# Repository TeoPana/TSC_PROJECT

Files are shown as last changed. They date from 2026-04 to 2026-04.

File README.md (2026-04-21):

# TSC_PROJECT
                    DIAGRAMA

                 +----------------------+
                 |      Baterie LiPo    |
                 +----------+-----------+
                            |
                            v
                 +----------------------+
                 |   Bloc alimentare    |
                 |  Charger / DC-DC     |
                 |  VBUS / VBAT / 3V3   |
                 +----------+-----------+
                            |
                            v
                 +----------------------+
                 |      nRF52840        |
                 | MCU + BLE + control  |
                 +---+---------+-----+--+
                     |         |     |
          SPI        |         |     | GPIO
                     |         |     |
                     v         v     v
          +---------------+  +-------------+  +-------------+
          |  Display      |  |  Senzori    |  |  Butoane    |
          |  e-paper      |  |  IMU / I2C  |  |  User Input |
          +---------------+  +-------------+  +-------------+

                     |
                     | SWD / test pads
                     v
              +------------------+
              | Debug / Program  |
              | SWDIO / SWDCLK   |
              +------------------+

                     |
                     | RF matching
                     v
              +------------------+
              | Antena 2.4 GHz   |
              +------------------+

USB-C ---> Alimentare / Service / Debug

Descriere Hardware - Proiect Smartwatch
Ce am vrut să fac aici e un smartwatch care are la bază microcontrolerul nRF52840. L-am ales pe ăsta pentru că e destul de puternic, are nucleu ARM Cortex-M4F și vine deja cu partea de radio de 2.4 GHz integrată, deci ne scapă de multe bătăi de cap cu comunicarea. El se ocupă de tot: display, butoane, baterie și partea de bluetooth.

1. Cum e gândit sistemul
Toată treaba e alimentată de o baterie mică Li-Po. Am pus niște test pad-uri pe placă ca să o putem lipi ușor. Tensiunea trece printr-un etaj de conversie (un DC/DC) și apoi pleacă spre restul componentelor.

În mare, piesa centrală (nRF-ul) coordonează:

Ecranul de tip e-paper (care consumă super puțin);

Senzorii de pe magistrala serială;

Butoanele pentru utilizator;

Partea de programare (debug) și antena de radio.

Cam astea ar fi blocurile mari: alimentare, procesorul, afișajul, butoanele și partea de RF.

2. Alimentarea
Bateria Li-Po e legată direct la PCB. Ca să scoatem 3.3 V pentru microcontroler am folosit un convertor DC/DC step-up (mă rog, e de tip step-down pentru că bateria are cam 3.7V-4.2V, dar ideea e că stabilizează rail-ul principal).

Am pus și condensatori de filtrare, de 100 nF, pe care i-am înghesuit cât mai aproape de pinii de alimentare, ca să nu avem zgomot. Traseele de curent le-am făcut mai groase pe cablaj ca să nu se încălzească sau să avem căderi de tensiune. Am mers pe DC/DC în loc de regulator liniar (LDO) ca să țină bateria mai mult, că la un ceas e critică autonomia.

3. Creierul sistemului (nRF52840)
Ăsta e punctul central. nRF-ul face de toate: citește butoanele, trimite date la ecran și se ocupă de stările de „sleep” ca să economisească energie. L-am pus cam pe mijlocul plăcii ca să fie traseele scurte către toate componentele și să nu se bată cap în cap semnalele digitale cu cele de radio.

4. Display-ul și cum se vede imaginea
Ecranul e legat prin SPI. Am ales SPI pentru că e mult mai rapid ca I2C-ul și la un ecran grafic chiar ai nevoie de viteză ca să nu se vadă cum se desenează pixelii.
Semnalele pe care le folosim sunt: MOSI pentru date, SCK (ceasul), CS (ca să știe display-ul că vorbim cu el) și mai sunt pinii de Reset și Busy.

Conectorul pentru display e pus pe margine, ca să poată intra panglica aia flexibilă în carcasă fără să se îndoaie prea tare sau să atingă alte piese.

5. Senzori și alte conexiuni
Pentru restul senzorilor am folosit magistrala I2C. E mai simplu așa că folosim doar doi pini (SDA și SCL) și putem pune mai mulți senzori pe aceleași fire. Am pus și rezistențe de pull-up, că altfel nu merge comunicarea pe I2C, e o greșeală clasică pe care am vrut să o evit.

6. Butoane (Input)
Am pus niște butoane fizice legate la pinii de tip GPIO. Din soft o să facem debouncing, dar pe parte de hardware sunt legate direct. Sunt puse pe margini ca să se pupe cu decupajele din carcasa printată.

7. USB-ul și programarea
Avem un conector USB-C pentru încărcare. Pentru programare n-am mai pus mufă specială că ocupa loc, așa că am scos niște pad-uri de test (SWDIO, SWDCLK, etc) unde ne putem lipi cu un programator extern când facem debug. E mult mai ok așa pentru faza de prototip.

8. Partea de antenă (RF)
Aici e cea mai sensibilă zonă. Am urmat schema de referință cu niște bobine și condensatori (rețeaua de adaptare) ca să avem impedanța de 50 ohmi.
Câteva reguli pe care le-am respectat la layout:

Antena e fix pe marginea plăcii;

Nu am pus masă (ground) sub antenă că altfel nu mai emite nimic;

Traseul e cât mai scurt, fără unghiuri dubioase care să bage paraziți.

9. Designul cablajului (Layout)
Am încercat să grupez piesele logic. Condensatorii de decuplare sunt „lipiți” de pinii de alimentare. N-am folosit unghiuri de 90 de grade la trasee (am mers pe 45) ca să arate profi și să evităm problemele de reflexie a semnalului. Am pus plan de masă pe ambele fețe și multe via-uri (via stitching) ca să fie totul ecranat bine, mai ales lângă zona de radio.

10. Bateria și consumul
Ceasul trebuie să stea aprins mult, deci am setat nRF-ul să stea în low-power cât mai mult timp. Ecranul e-paper ajută enorm aici, că el consumă curent doar când schimbi imaginea, în rest stă „degeaba”. Dacă nu facem refresh des, bateria ar trebui să țină destul de bine.

11. Cum se asamblează toate (Mecanică)
În modelul 3D am verificat dacă încap toate: PCB-ul, bateria Li-Po (care e destul de grasă) și ecranul. Mufa USB-C trebuie să iasă fix prin gaura din carcasă, altfel nu putem băga cablul la încărcat. Per total, totul pare că se aliniază ok și nu există piese care să se lovească între ele.

## Bill of Materials (BOM)

| Ref | Componentă | Valoare | Package | JLC Part | Datasheet |
|-----|---|---|---|---|---|
| C5, C7, C8, C12, C19 | Condensator decuplare | 100nF | 0201 | C1525 | https://datasheet.lcsc.com/lcsc/1811091111_Murata-Electronics-GRM011R60J104KE01D_C1525.pdf |
| C23, C27, C34, C42 | Condensator | 100nF | 0201 | C1525 | https://datasheet.lcsc.com/lcsc/1811091111_Murata-Electronics-GRM011R60J104KE01D_C1525.pdf |
| C15 | Condensator | 1µF | 0402 | C52923 | https://datasheet.lcsc.com/lcsc/1811151714_Samsung-Electro-Mechanics-CL05A105KO5NNNC_C52923.pdf |
| C24, C39 | Condensator bulk | 10µF | 0402 | C19702 | https://datasheet.lcsc.com/lcsc/1811091111_Samsung-Electro-Mechanics-CL05A106MQ5NUNC_C19702.pdf |
| C11 | Condensator RF | 100pF | 0201 | C57112 | https://datasheet.lcsc.com/lcsc/1811151714_Samsung-Electro-Mechanics-CL03C101JB3NNNC_C57112.pdf |
| R5, R7, R8 | Rezistor | 10kΩ | 0201 | C25744 | https://datasheet.lcsc.com/lcsc/1811090913_Yageo-RC0201FR-0710KL_C25744.pdf |
| R9, R_PWR_EPD | Rezistor | 10kΩ | 0201 | C25744 | https://datasheet.lcsc.com/lcsc/1811090913_Yageo-RC0201FR-0710KL_C25744.pdf |
| L2 | Inductor | 10µH | 0402 | C1046 | https://datasheet.lcsc.com/lcsc/1811091211_Sunlord-SWPA4020S100MT_C1046.pdf |
| SJ1 | Jumper | - | SMD | - | - |
| U1 | Microcontroller | nRF52840 | QFN/BGA | C87453 | https://infocenter.nordicsemi.com/pdf/nRF52840_PS_v1.1.pdf |
| USB | Conector USB-C | - | SMD | C165948 | https://datasheet.lcsc.com/lcsc/1811151713_TYPE-C-16PIN_C165948.pdf |
Toate componentele au fost selectate din biblioteca JLCPCB pentru a asigura compatibilitatea cu procesul de asamblare automată.

PINII nRF52840

Pinii i-am ales în funcție de cum dădea mai bine pe layout-ul PCB-ului și cum se optimiza mai ușor rutarea. Perifericele, gen SPI și I2C, le-am mapat pe pinii care erau cei mai aproape de componentele lor, special ca să ținem traseele scurte și să nu avem zgomot pe semnal.

Pinii cu funcții speciale (SWD și resetul) i-am lăsat doar pentru partea de debug, nu i-am folosit la alte semnale de uz general ca să nu ne încurcăm. Pentru semnalele de viteză mare, cum e SPI-ul, am mers pe conexiuni cât mai scurte și directe, în timp ce pe alea mai lente (I2C sau GPIO-urile) le-am plasat mai flexibil, pe unde am mai găsit loc pe placă.

Aveam si componenta 3D a TC2030-IDC ului, dar dupa ce am vorbit cu laborantul despre problema ca nu ar incapea in carcasa toate acele cabluri, mi s-a spus ca trebuie sa sterg acel model, si doar sa pun un rectangle deasupra lui ca sa acopar acele gauri.

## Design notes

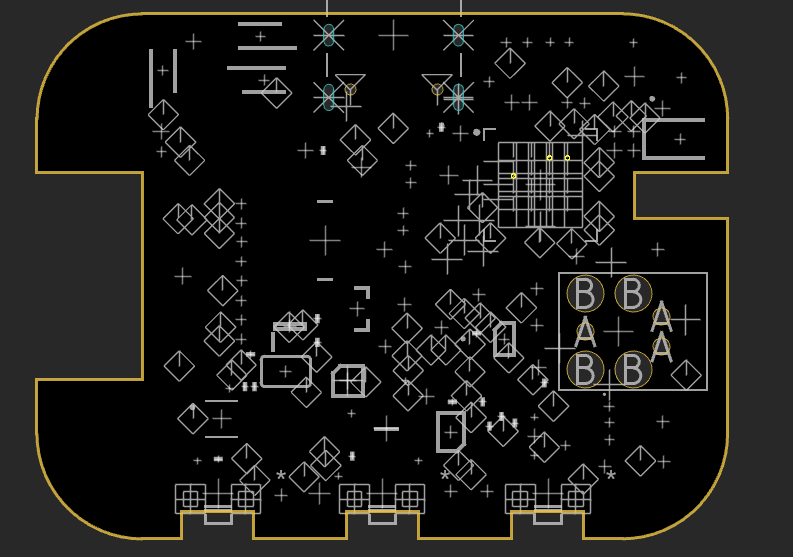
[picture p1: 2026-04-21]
Images/Screenshot 2026-04-21 045611.png

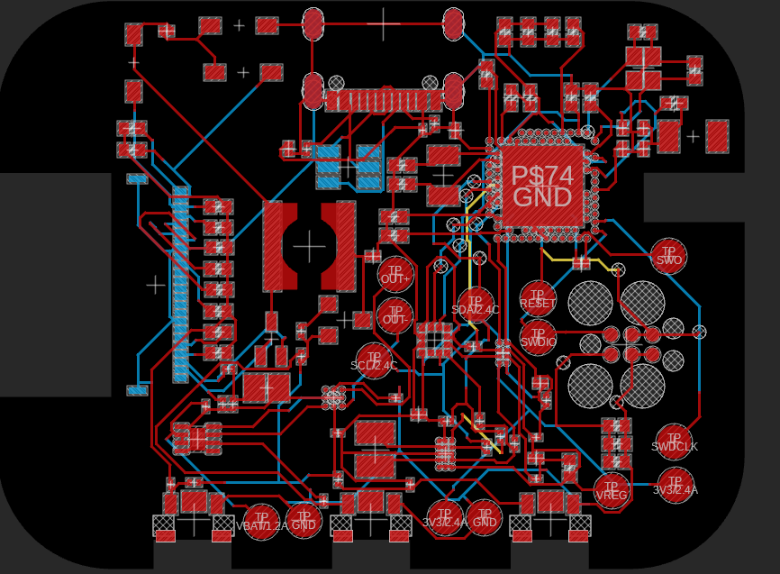
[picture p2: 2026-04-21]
Images/Screenshot 2026-04-21 045701.png

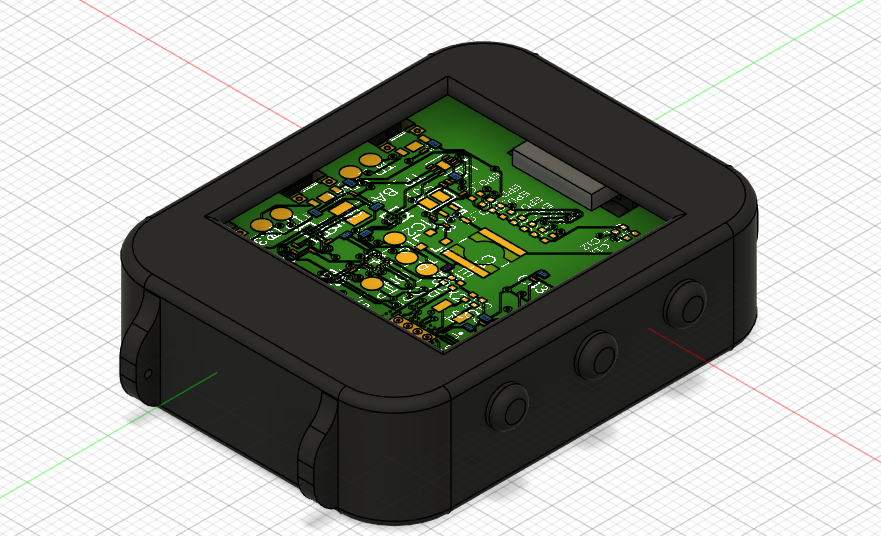
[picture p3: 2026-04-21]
Images/Screenshot 2026-04-21 045815.png

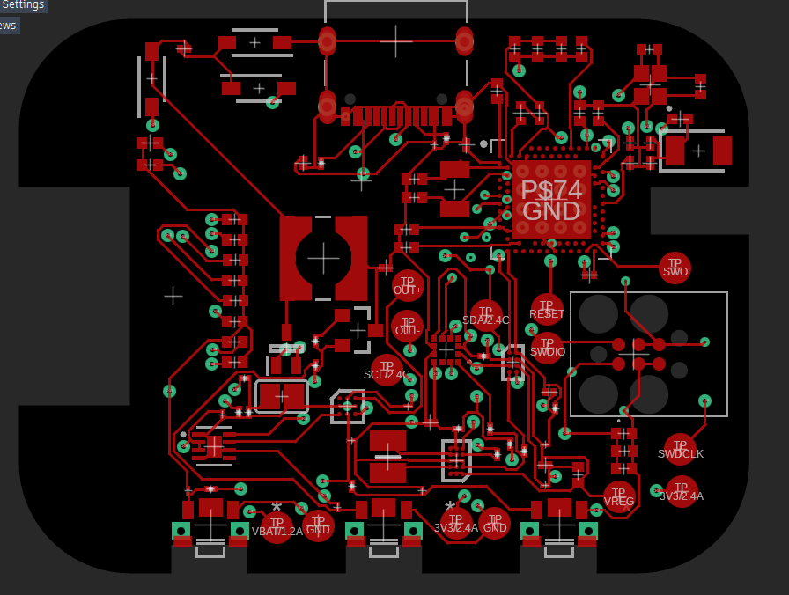
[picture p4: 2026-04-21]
Images/Screenshot 2026-04-21 045517.png

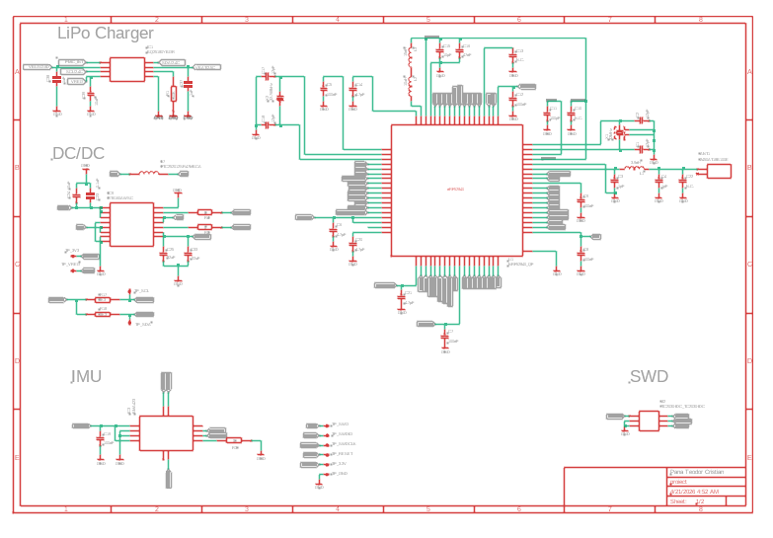
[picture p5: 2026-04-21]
Images/Screenshot 2026-04-21 045401.png

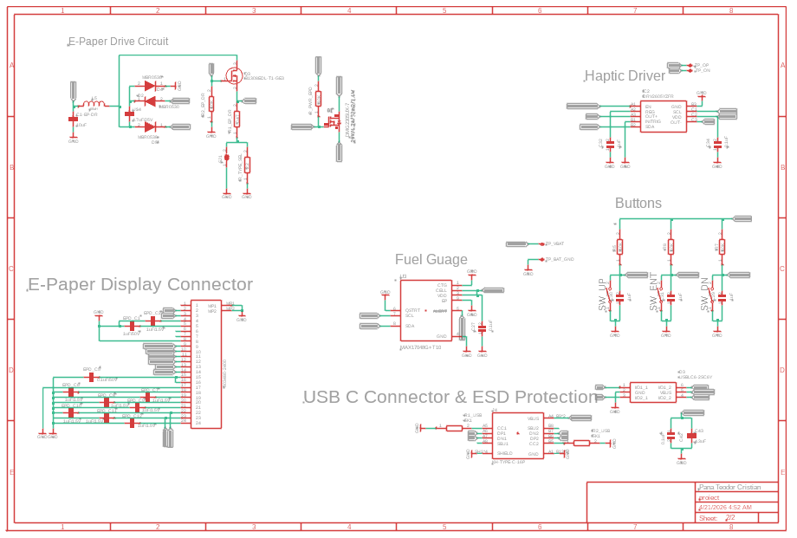
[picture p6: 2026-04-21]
Images/Screenshot 2026-04-21 045320.png

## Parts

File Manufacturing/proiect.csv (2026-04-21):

Qty | Value | Device | Package | Parts | Description | ARROW_PART_NUMBER | ARROW_PRICE-STOCK | AVAILABILITY | CHECK_PRICES | COPYRIGHT | DESCRIPTION | DIGI-KEY_PART_NUMBER_1 | DIGI-KEY_PART_NUMBER_2 | DIGI-KEY_PART_NUMBER_3 | HEIGHT | JLCPCB | MANUFACTURER_NAME | MANUFACTURER_PART_NUMBER | MF | MFR_NAME | MOUSER_PART_NUMBER | MOUSER_PRICE-STOCK | MP | PACKAGE | POPULARITY | PRICE | PROD_ID | PURCHASE-URL | SNAPEDA_LINK | TP_SIGNAL_NAME | VALUE
1 |  | ESP32_C6_LIBRARY_7_JUMPER_SJ | ESP32_C6_LIBRARY_7_JUMPER_SJ | SJ1 | SMD solder JUMPER |  |  |  |  |  |  |  |  |  |  |  |  |  |  |  |  |  |  |  | 3
3 | 0 | CPF0201D7K68C1_CPF0201D7K68C1 | CPF0201D7K68C1_0201 | R2, R3, R4 | 7.68k 0201 Thin Film Surface Mount Fixed Resistor +/-0.5% 0.031W CPF0201D7K68C1
4 | 0.1uF | GRM011R60J152KE01L_2_GRM011R60J152KE01L | GRM011R60J152KE01L_2_CAPC0201X13N | C23, C27, C34, C42 | Check availability |  |  | In Stock | https://www.snapeda.com/parts/GRM011R60J152KE01L/Murata/view-part/?ref=eda |  | SMD Capacitor X5R(EIA) with Capacitance: 1500pF Tol. 10%. Rated Voltage: 6.3Vdc |  |  |  |  |  |  |  | Murata |  |  |  | GRM011R60J152KE01L | 0201 Murata |  | None |  |  | https://www.snapeda.com/parts/GRM011R60J152KE01L/Murata/view-part/?ref=snap
1 | 0.1uF/50V | PERFECT_0402_CAP_0402 | PERFECT_0402_0402 | EPD_C5 | 0402 (1005 Metric)
1 | 0.47 | CPF0201D7K68C1_CPF0201D7K68C1 | CPF0201D7K68C1_0201 | R1_EP_DR | 7.68k 0201 Thin Film Surface Mount Fixed Resistor +/-0.5% 0.031W CPF0201D7K68C1
4 | 100nF | NORDIC_NRF_3_CAPACITOR_0201_L | NORDIC_NRF_3_RESC0201_L | C5, C7, C8, C9 | Generic chip capacitor
2 | 100nF | PERFECT_0402_CAP_0402 | PERFECT_0402_0402 | C12, C19 | 0402 (1005 Metric)
1 | 100pF | PERFECT_0402_CAP_0402 | PERFECT_0402_0402 | C11 | 0402 (1005 Metric)
6 | 10K | CPF0201D7K68C1_CPF0201D7K68C1 | CPF0201D7K68C1_0201 | R1, R2_EP_DR, R5, R7, R8, R_PWR_EPD | 7.68k 0201 Thin Film Surface Mount Fixed Resistor +/-0.5% 0.031W CPF0201D7K68C1
2 | 10uF | NORDIC_NRF_3_CAPACITOR_0201_L | NORDIC_NRF_3_RESC0201_L | C1-EP-DR, C39 | Generic chip capacitor
1 | 10uF | PERFECT_0402_CAP_0402 | PERFECT_0402_0402 | C24 | 0402 (1005 Metric)
1 | 10uH | NORDIC_NRF_2_INDUCTOR_0402_L | NORDIC_NRF_2_RESC0402_L | L2 | Generic chip inductor
1 | 10µF | PERFECT_0402_CAP_0402 | PERFECT_0402_0402 | C15 | 0402 (1005 Metric)
4 | 12pF | PERFECT_0402_CAP_0402 | PERFECT_0402_0402 | C1, C2, C17, C18 | 0402 (1005 Metric)
1 | 15nH | NORDIC_NRF_2_INDUCTOR_0402_L | NORDIC_NRF_2_RESC0402_L | L3 | Generic chip inductor
2 | 1pF | NORDIC_NRF_3_CAPACITOR_0201_L | NORDIC_NRF_3_RESC0201_L | C3, C4 | Generic chip capacitor
1 | 1uF | GRM011R60J152KE01L_1_GRM011R60J152KE01L | GRM011R60J152KE01L_1_0201 | C38 | Check availability
5 | 1uF | GRM011R60J152KE01L_2_GRM011R60J152KE01L | GRM011R60J152KE01L_2_CAPC0201X13N | C29\, C30, C31, C32, C37 | Check availability |  |  | In Stock | https://www.snapeda.com/parts/GRM011R60J152KE01L/Murata/view-part/?ref=eda |  | SMD Capacitor X5R(EIA) with Capacitance: 1500pF Tol. 10%. Rated Voltage: 6.3Vdc |  |  |  |  |  |  |  | Murata |  |  |  | GRM011R60J152KE01L | 0201 Murata |  | None |  |  | https://www.snapeda.com/parts/GRM011R60J152KE01L/Murata/view-part/?ref=snap
8 | 1uF/1.5V | PERFECT_0402_CAP_0402 | PERFECT_0402_0402 | EPD_C2, EPD_C6, EPD_C7, EPD_C8, EPD_C9, EPD_C10, EPD_C11, EPD_C12 | 0402 (1005 Metric)
1 | 1uF/50V | PERFECT_0402_CAP_0402 | PERFECT_0402_0402 | EPD_C1 | 0402 (1005 Metric)
1 | 2.2 | CPF0201D7K68C1_CPF0201D7K68C1 | CPF0201D7K68C1_0201 | R_TYPE_SEL | 7.68k 0201 Thin Film Surface Mount Fixed Resistor +/-0.5% 0.031W CPF0201D7K68C1
3 | 2025-10-22_07-23-44_LIBRARY_EVP-AKE31ASW_EVP-AKE31A_PAN | 2025-10-22_07-23-44_LIBRARY_EVP-AKE31ASW_EVP-AKE31A_PAN | 2025-10-22_07-23-44_LIBRARY_SW_EVP-AKE31A_PAN | SW_DN, SW_ENT, SW_UP |  |  |  |  |  | Copyright (C) 2025 Ultra Librarian. All rights reserved. |  | P123437TR-ND | P123437CT-ND | P123437DKR-ND |  |  | Panasonic | EVP-AKE31A
1 | 20V/4.2A/52m?/1.4W | ESP32_C6_LIBRARY_4_ESP32_WROVER_SPARKFUN-DISCRETESEMI_MOSFET_PCH-DMG2305UX-7 | ESP32_C6_LIBRARY_4_ESP32_C6_LIBRARY_4_ESP32_C6_LIBRARY_4_ESP32_C6_LIBRARY_4_ESP32_WROVER_SPARKFUN-DISCRETESEMI_SOT23-3 | Q1 | P-channel MOSFETs |  |  |  |  |  |  |  |  |  |  |  |  |  |  |  |  |  |  |  |  |  | TRAN-14388 |  |  |  | 20V/4.2A/52m?/1.4W
2 | 22uF | PERFECT_0402_CAP_0402 | PERFECT_0402_0402 | C25, C33 | 0402 (1005 Metric)
1 | 2450AT18B100E | 2450AT18B100E_2450AT18B100E | 2450AT18B100E_ANTC3216X140N | ANT1 | Antennas 2.45GHz ANTENNA | 2450AT18B100E | https://www.arrow.com/en/products/2450at18b100e/johanson-dielectrics?utm_currency=USD&region=nac |  |  |  | Antennas 2.45GHz ANTENNA |  |  |  | 1.4mm |  | JOHANSON TECHNOLOGY | 2450AT18B100E |  |  | 609-2450AT18B100E | https://www.mouser.co.uk/ProductDetail/Johanson-Technology/2450AT18B100E?qs=yCnrNFeXz%252Bh5MFsFIXGZGA%3D%3D
1 | 3.9nH | NORDIC_NRF_2_INDUCTOR_0402_L | NORDIC_NRF_2_RESC0402_L | L1 | Generic chip inductor
1 | 32.768kHz | NORDIC_NRF_1_XTAL_32KHZ | NORDIC_NRF_1_XTAL_3215_N | X2
1 | 32MHz | NORDIC_NRF_XTAL_32MHZ | NORDIC_NRF_BT-XTAL_2016_N | X1
2 | 3K3 | CPF0201D7K68C1_CPF0201D7K68C1 | CPF0201D7K68C1_0201 | R17, R18 | 7.68k 0201 Thin Film Surface Mount Fixed Resistor +/-0.5% 0.031W CPF0201D7K68C1
1 | 4.3uF | NORDIC_NRF_3_CAPACITOR_0201_L | NORDIC_NRF_3_RESC0201_L | C43 | Generic chip capacitor
1 | 4.7uF/25V | NORDIC_NRF_3_CAPACITOR_0201_L | NORDIC_NRF_3_RESC0201_L | U$4 | Generic chip capacitor
1 | 4.7µF | NORDIC_NRF_3_CAPACITOR_0201_L | NORDIC_NRF_3_RESC0201_L | C21 | Generic chip capacitor
3 | 4.7µF | PERFECT_0402_CAP_0402 | PERFECT_0402_0402 | C6, C14, C20 | 0402 (1005 Metric)
1 | 47nF | PERFECT_0402_CAP_0402 | PERFECT_0402_0402 | C16 | 0402 (1005 Metric)
1 | 503480-2400 | 503480-2400_503480-2400 | 503480-2400_5034802400 | J1 | FFC & FPC Connectors 0.5mm FPC RA SMT Dual Contact 24Ckt |  |  |  |  |  | FFC & FPC Connectors 0.5mm FPC RA SMT Dual Contact 24Ckt |  |  |  | 1.87mm |  | Molex | 503480-2400 |  |  | 538-503480-2400 | https://www.mouser.co.uk/ProductDetail/Molex/503480-2400?qs=OAhjpuo3Vu7efIoxFh9AOw%3D%3D
2 | 5K1 | CPF0201D7K68C1_CPF0201D7K68C1 | CPF0201D7K68C1_0201 | R1_USB, R2_USB | 7.68k 0201 Thin Film Surface Mount Fixed Resistor +/-0.5% 0.031W CPF0201D7K68C1
1 | 68uH | ESP32_C6_LIBRARY_2_744043680IND_4828-WE-TPC_WRE | ESP32_C6_LIBRARY_2_IND_4828-WE-TPC_WRE | L5 |  |  |  |  |  | Copyright (C) 2024 Ultra Librarian. All rights reserved. |  |  |  |  |  |  |  | 744043680 |  | Wurth Electronics
1 | BMA423 | BMA423_BMA423 | BMA423_BMA423 | IC3 | Accelerometers Triaxial low-g 12bit Acceleration Sensor | BMA423 | https://www.arrow.com/en/products/bma423/bosch |  |  |  | Accelerometers Triaxial low-g 12bit Acceleration Sensor |  |  |  | 1mm |  | BOSCH | BMA423 |  |  | 262-BMA423 | https://www.mouser.co.uk/ProductDetail/Bosch-Sensortec/BMA423?qs=HXFqYaX1Q2xC%252BSgeGoX3mg%3D%3D
1 | BQ25180YBGR | BQ25180YBGR_BQ25180YBGR | BQ25180YBGR_BGA8C40P2X4_100X155X50 | IC1 | Charger IC Lithium Ion/Polymer, Lithium Iron Phosphate 8-DSBGA (1.6x1.1) | BQ25180YBGR | https://www.arrow.com/en/products/bq25180ybgr/texas-instruments?utm_currency=USD&region=nac |  |  |  | Charger IC Lithium Ion/Polymer | Lithium Iron Phosphate 8-DSBGA (1.6x1.1) |  |  |  | 0.5mm |  | Texas Instruments | BQ25180YBGR |  |  | 595-BQ25180YBGR | https://www.mouser.co.uk/ProductDetail/Texas-Instruments/BQ25180YBGR?qs=doiCPypUmgEWjAK%252BJAX6Tw%3D%3D
1 | DRV2605YZFR | DRV2605YZFR_DRV2605YZFR | DRV2605YZFR_BGA9C50P3X3_144X144X62 | IC2 | Haptic Driver for ERM/LRA with Built-In Library and Smart Loop Architecture | DRV2605YZFR | https://www.arrow.com/en/products/drv2605yzfr/texas-instruments?region=nac |  |  |  | Haptic Driver for ERM/LRA with Built-In Library and Smart Loop Architecture |  |  |  | 0.625mm |  | Texas Instruments | DRV2605YZFR
1 | FTC252012SR47MBCA | MLP2016SR47MT0S1_FTC252012SR47MBCA | MLP2016SR47MT0S1_INDC2016X100N | L7 | SMD / SMT Inductors (Coils), L=0.47?H, L x W x T : |  |  |  |  |  | SMD / SMT Inductors (Coils) | L=0.47?H | L x W x T : |  |  |  | 1mm | https://jlcpcb.com/partdetail/6763488-FTC252012SR47MBCA/C5832368 | TDK | FTC252012SR47MBCA
14 | HECTOR_WATCH_1_TPTP20R | HECTOR_WATCH_1_TPTP20R | HECTOR_WATCH_1_TP20R | TP_3.3V, TP_3V3, TP_BAT_GND, TP_GND, TP_ON, TP_OP, TP_RESET, TP_SCL, TP_SDA, TP_SWDCLK, TP_SWDIO, TP_SWO, TP_VBAT, TP_VREG | Test pad |  |  |  |  |  |  |  |  |  |  |  |  |  |  |  |  |  |  |  | 2
1 | KH-TYPE-C-16P | KH-TYPE-C-16P_KH-TYPE-C-16P | KH-TYPE-C-16P_KINGHELM_KH-TYPE-C-16P | J4 | Check availability |  |  | Not in stock | https://www.snapeda.com/parts/KH-TYPE-C-16P/Kinghelm/view-part/?ref=eda |  |  |  |  |  |  |  |  |  | kinghelm |  |  |  | KH-TYPE-C-16P | None |  | None |  |  | https://www.snapeda.com/parts/KH-TYPE-C-16P/Kinghelm/view-part/?ref=snap
1 | MAX17048G+T10 | ESP32_C6_LIBRARY_MAX17048G+T10 | ESP32_C6_LIBRARY_SON50P200X200X80-9N | U3 | Check availability |  |  | In Stock | https://www.snapeda.com/parts/MAX17048G+T10/Analog+Devices/view-part/?ref=eda |  | 3µA 1-Cell/2-Cell Fuel Gauge with ModelGauge |  |  |  |  |  |  |  | Analog Devices |  |  |  | MAX17048G+T10 | TDFN-8 Maxim |  | None |  | https://www.snapeda.com/api/url_track_click_mouser/?unipart_id=329239&manufacturer=Analog Devices&part_name=MAX17048G+T10&search_term=None | https://www.snapeda.com/parts/MAX17048G+T10/Analog+Devices/view-part/?ref=snap
3 | MBR0530 | ESP32_C6_LIBRARY_5_MBR0530 | ESP32_C6_LIBRARY_5_SOD3716X135N | D2, D4, D5 | ON SEMICONDUCTOR - MBR0530 - DIODE, SCHOTTKY, 0.5A, 30V, SOD-123 |  |  | In Stock | https://www.snapeda.com/parts/MBR0530/Onsemi/view-part/?ref=eda |  | Diode Schottky 30 V 500mA Surface Mount SOD-123 |  |  |  |  |  |  |  | ON Semiconductor |  |  |  | MBR0530 | SOD-123-2 ON Semiconductor |  | None |  | https://www.snapeda.com/api/url_track_click_mouser/?unipart_id=179458&manufacturer=ON Semiconductor&part_name=MBR0530&search_term=None | https://www.snapeda.com/parts/MBR0530/Onsemi/view-part/?ref=snap
1 | N.C. | NORDIC_NRF_3_CAPACITOR_0201_L | NORDIC_NRF_3_RESC0201_L | C22 | Generic chip capacitor
2 | N.C. | PERFECT_0402_CAP_0402 | PERFECT_0402_0402 | C10, C13 | 0402 (1005 Metric)
1 | NRF52840_QF | NORDIC_NRF_4_NRF52840_QF | NORDIC_NRF_4_AQFN50P700X700X85_HS-74N | U1 | nRF52840
1 | RT6160AWSC | RT6160AWSC_RT6160AWSC | RT6160AWSC_BGA15C40P3X5_140X230X60 | IC9 | Buck-Boost Regulator Positive Output Step-Up/Step-Down I2C DC-DC Controller IC 15-WL-CSP (BSC) (1.4x2.3) |  |  |  |  |  | Buck-Boost Regulator Positive Output Step-Up/Step-Down I2C DC-DC Controller IC 15-WL-CSP (BSC) (1.4x2.3) |  |  |  | 0.6mm |  | RICHTEK | RT6160AWSC |  |  | 835-RT6160AWSC | https://www.mouser.co.uk/ProductDetail/Richtek/RT6160AWSC?qs=amGC7iS6iy%2FLd9PSoixZXQ%3D%3D
1 | TC2030-IDC_TC2030-IDC | TC2030-IDC_TC2030-IDC | TC2030-IDC_TC2030IDC | J2 | CABLE ADAPTER 6 POS |  |  |  |  |  | CABLE ADAPTER 6 POS |  |  |  | 19mm |  | Tag Connect | TC2030-IDC
1 | USBLC6-2SC6Y | ESP32_C6_LIBRARY_3_USBLC6-2SC6Y | ESP32_C6_LIBRARY_3_SOT95P280X145-6N | D3 | Low Cap. ESD Protection Auto SOT-23-6 STMicroelectronics USBLC6-2SC6Y, Dual Uni-Directional TVS Diode Array, 6-Pin SOT-23 |  |  | In Stock | https://www.snapeda.com/parts/USBLC6-2SC6Y/STMicroelectronics/view-part/?ref=eda |  | 17V Clamp 5A (8/20µs) Ipp Tvs Diode Surface Mount SOT-23-6 |  |  |  |  |  |  |  | STMicroelectronics |  |  |  | USBLC6-2SC6Y | SOT-23-6 STMicroelectronics |  | None |  |  | https://www.snapeda.com/parts/USBLC6-2SC6Y/STMicroelectronics/view-part/?ref=snap
1 | \SI1308EDL-T1-GE3 | ESP32_C6_LIBRARY_6_SI1308EDL-T1-GE3 | ESP32_C6_LIBRARY_6_SOT65P210X110-3N | Q3 | MOSFET N-Ch 30V 1.5A TrenchFET SC70 Vishay Si1308EDL-T1-GE3 N-channel MOSFET Transistor, 1.5 A, 30 V, 3-Pin SC-70 |  |  | In Stock | https://www.snapeda.com/parts/SI1308EDL-T1-GE3/Vishay+Siliconix/view-part/?ref=eda |  | Si1308EDL-T1-GE3 N-channel MOSFET Transistor | 1.5 A | 30 V | 3-Pin SC-70 | Siliconix / Vishay SI1308EDL-T1-GE3 |  |  |  |  |  |  |  | Vishay Siliconix |  |  |  | SI1308EDL-T1-GE3 | SOT-323 Vishay Semiconductor |  | None |  | https://www.snapeda.com/api/url_track_click_mouser/?unipart_id=274603&manufacturer=Vishay Siliconix&part_name=SI1308EDL-T1-GE3&search_term=None

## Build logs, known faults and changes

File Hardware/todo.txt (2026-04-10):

deci am super gresit condensatoarele si imi vine sa ma dau cu capul de pereti.
pcb ul il fac degeaba daca o luam asa.
m-am apucat de el dar nu merge sa dau save pt ca zice ca e out of date sau some shit.
o sa tin laptopul deschis ca nu am chef sa refac totul acum.
sper sa fi permisiv/a cu schematica macar.
pwp ai grija.

la restul todo urilor nu zic nimic deci nu te strofoca sa le deschizi, nu e nmc acolo.

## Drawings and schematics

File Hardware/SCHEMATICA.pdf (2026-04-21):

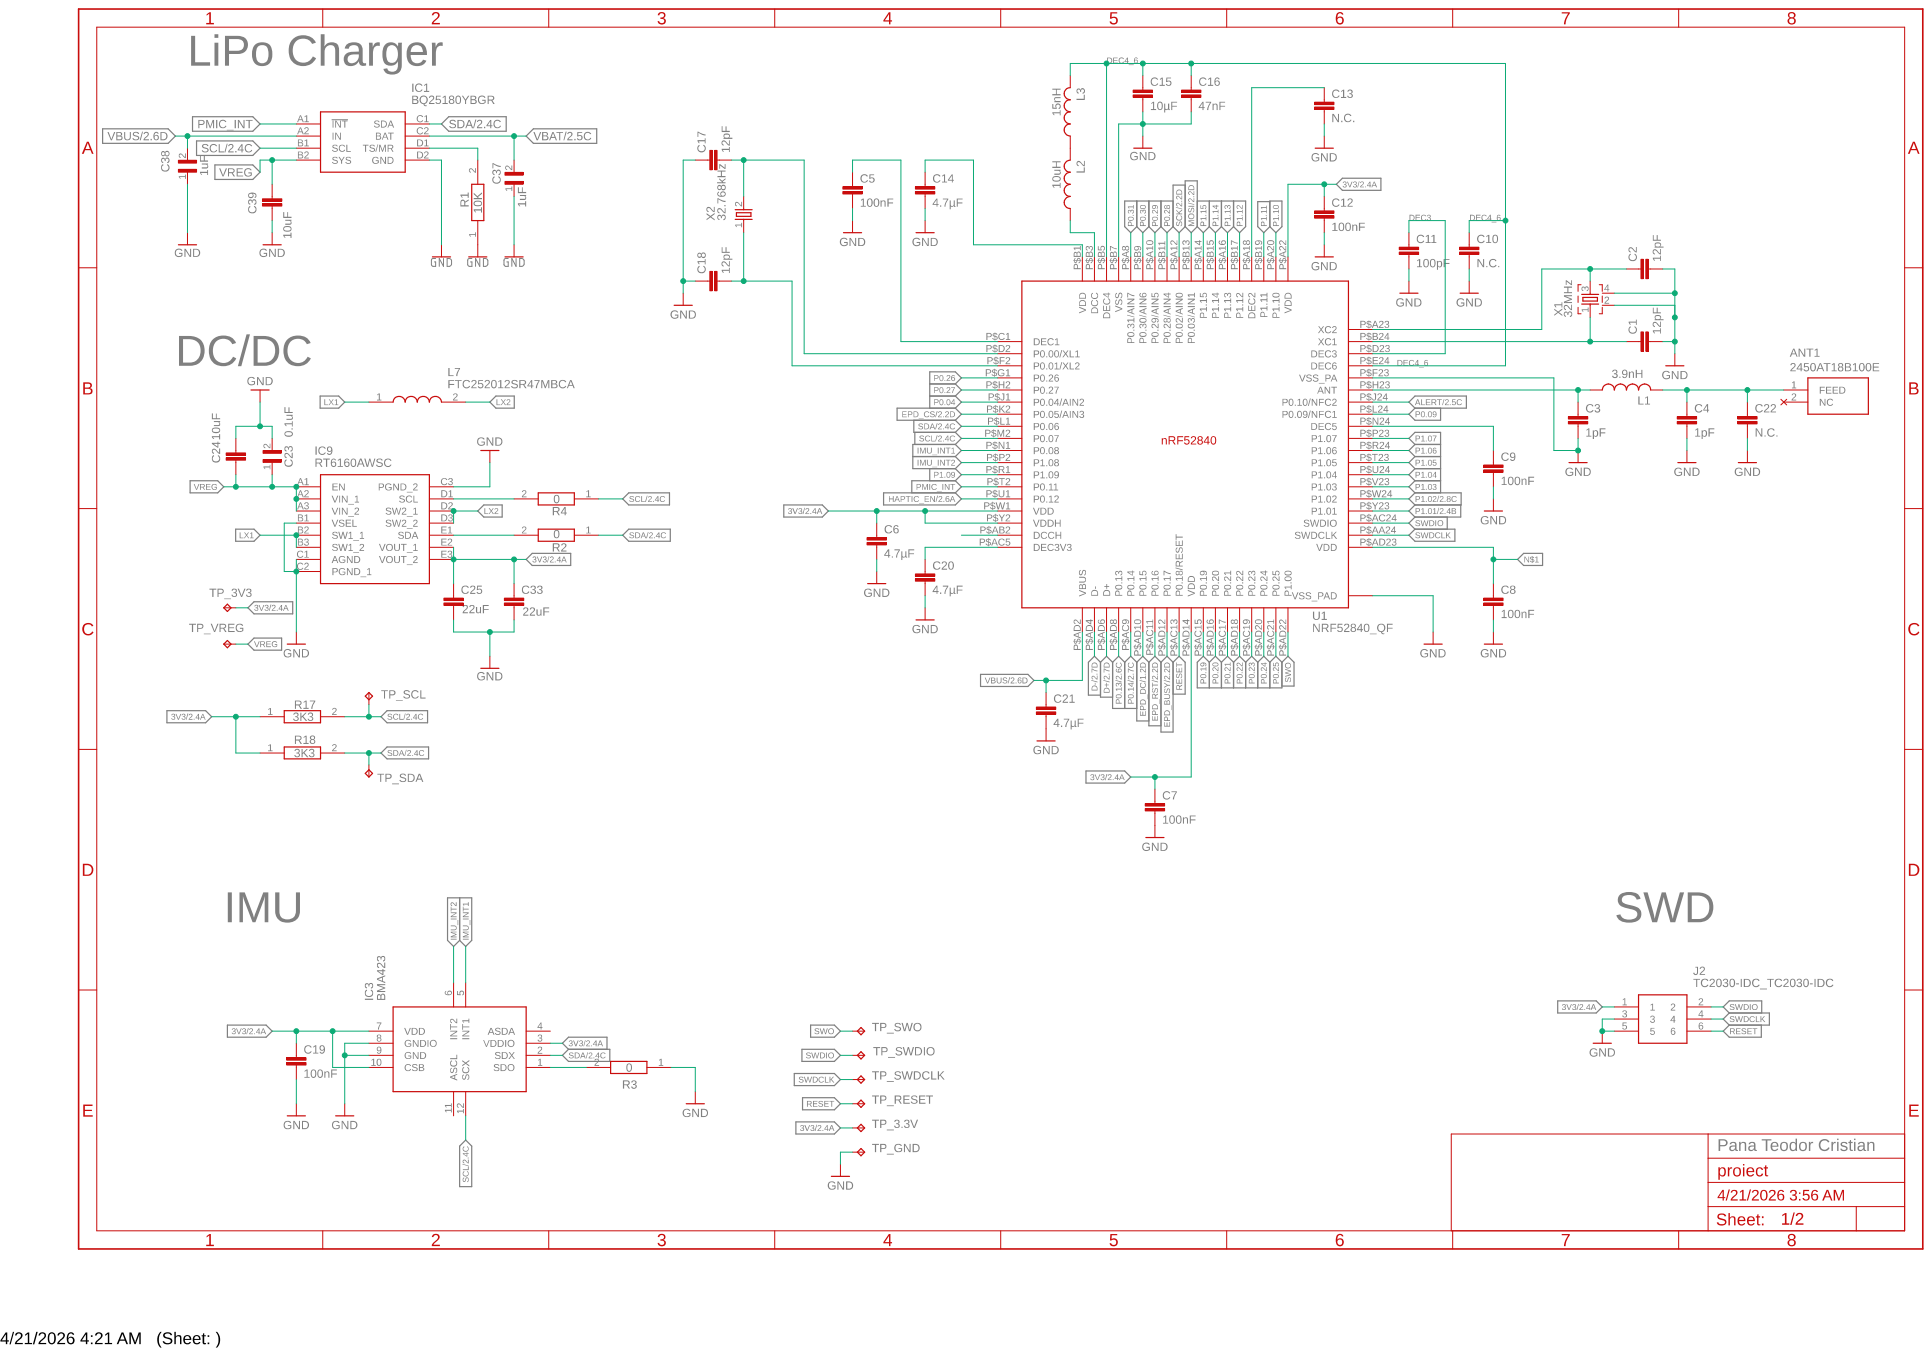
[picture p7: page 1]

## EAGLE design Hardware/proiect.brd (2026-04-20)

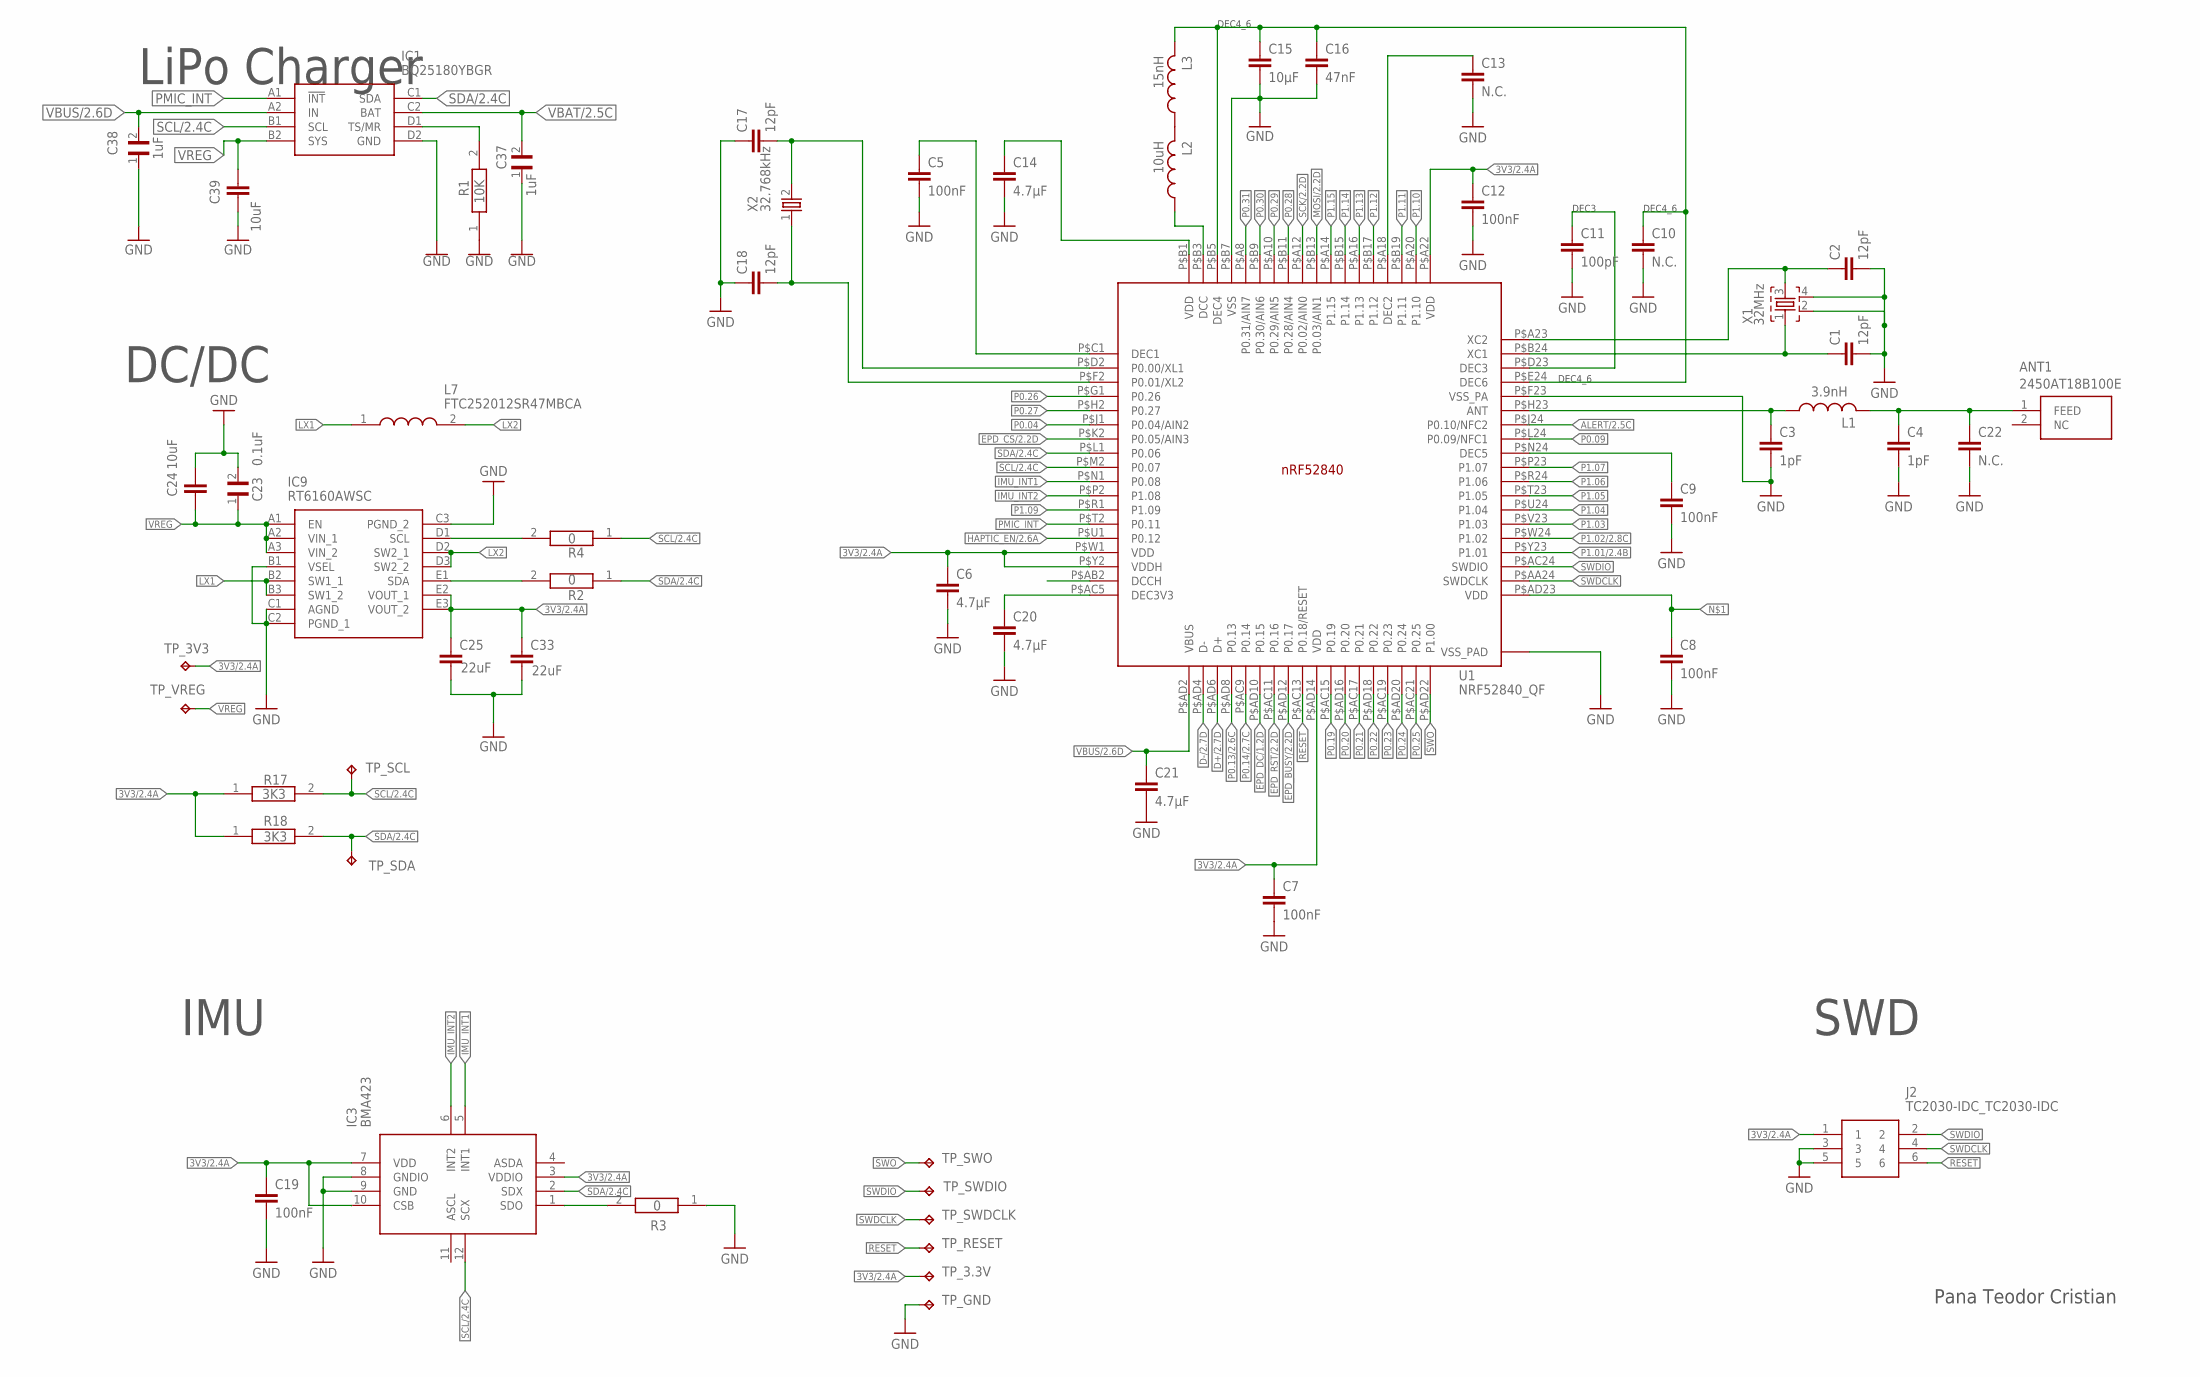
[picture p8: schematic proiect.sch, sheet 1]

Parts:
ANT1: 2450AT18B100E; 2450AT18B100E_ANTC3216X140N
C1, C2, C17, C18: 12pF; PERFECT_0402_0402
C3, C4: 1pF; NORDIC_NRF_3_RESC0201_L
C5, C7, C8, C9: 100nF; NORDIC_NRF_3_RESC0201_L
C6, C14, C20: 4.7µF; PERFECT_0402_0402
C10, C13: N.C.; PERFECT_0402_0402
C11: 100pF; PERFECT_0402_0402
C12, C19: 100nF; PERFECT_0402_0402
C15: 10µF; PERFECT_0402_0402
C16: 47nF; PERFECT_0402_0402
C21: 4.7µF; NORDIC_NRF_3_RESC0201_L
C22: N.C.; NORDIC_NRF_3_RESC0201_L
C23: 0.1uF; GRM011R60J152KE01L_2_CAPC0201X13N
C24: 10uF; PERFECT_0402_0402
C25, C33: 22uF; PERFECT_0402_0402
C37: 1uF; GRM011R60J152KE01L_2_CAPC0201X13N
C38: 1uF; GRM011R60J152KE01L_1_0201
C39: 10uF; NORDIC_NRF_3_RESC0201_L
IC1: BQ25180YBGR; BQ25180YBGR_BGA8C40P2X4_100X155X50
IC3: BMA423; BMA423_BMA423
IC9: RT6160AWSC; RT6160AWSC_BGA15C40P3X5_140X230X60
J2: TC2030-IDC_TC2030-IDC; TC2030-IDC_TC2030IDC
L1: 3.9nH; NORDIC_NRF_2_RESC0402_L
L2: 10uH; NORDIC_NRF_2_RESC0402_L
L3: 15nH; NORDIC_NRF_2_RESC0402_L
L7: FTC252012SR47MBCA; MLP2016SR47MT0S1_INDC2016X100N
R1: 10K; CPF0201D7K68C1_0201
R2, R3, R4: 0; CPF0201D7K68C1_0201
R17, R18: 3K3; CPF0201D7K68C1_0201
TP_3.3V, TP_3V3: HECTOR_WATCH_1_TPTP20R; HECTOR_WATCH_1_TP20R
TP_GND: HECTOR_WATCH_1_TPTP20R; HECTOR_WATCH_1_TP20R
TP_RESET: HECTOR_WATCH_1_TPTP20R; HECTOR_WATCH_1_TP20R
TP_SCL: HECTOR_WATCH_1_TPTP20R; HECTOR_WATCH_1_TP20R
TP_SDA: HECTOR_WATCH_1_TPTP20R; HECTOR_WATCH_1_TP20R
TP_SWDCLK: HECTOR_WATCH_1_TPTP20R; HECTOR_WATCH_1_TP20R
TP_SWDIO: HECTOR_WATCH_1_TPTP20R; HECTOR_WATCH_1_TP20R
TP_SWO: HECTOR_WATCH_1_TPTP20R; HECTOR_WATCH_1_TP20R
TP_VREG: HECTOR_WATCH_1_TPTP20R; HECTOR_WATCH_1_TP20R
U1: NRF52840_QF; NORDIC_NRF_4_AQFN50P700X700X85_HS-74N
X1: 32MHz; NORDIC_NRF_BT-XTAL_2016_N
X2: 32.768kHz; NORDIC_NRF_1_XTAL_3215_N

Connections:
3V3/2.4A: C6.1, C7.1, C12.1, C19.1, C25.1, C33.1, IC3.3 (VDDIO), IC3.7 (VDD), IC3.10 (CSB), IC9.E2 (VOUT_1), IC9.E3 (VOUT_2), J2.1, R17.1, R18.1, TP_3.3V.TP, TP_3V3.TP, U1.P$A22 (VDD), U1.P$AD14 (VDD), U1.P$W1 (VDD), U1.P$Y2 (VDDH)
ALERT/2.5C: U1.P$J24 (P0.10/NFC2)
D+/2.7D: U1.P$AD6 (D+)
D-/2.7D: U1.P$AD4 (D-)
EPD_BUSY/2.2D: U1.P$AD12 (P0.17)
EPD_CS/2.2D: U1.P$K2 (P0.05/AIN3)
EPD_DC/1.2D: U1.P$AD10 (P0.15)
EPD_RST/2.2D: U1.P$AC11 (P0.16)
GND: C1.2, C2.2, C3.2, C4.2, C5.2, C6.2, C7.2, C8.2, C9.2, C10.2, C11.2, C12.2, C13.2, C14.2, C15.2, C16.2, C17.1, C18.1, C19.2, C20.2, C21.2, C22.2, C23.2, C24.1, C25.2, C33.2, C37.1, C38.1, C39.2, IC1.D2 (GND), IC3.8 (GNDIO), IC3.9 (GND), IC9.B1 (VSEL), IC9.C1 (AGND), IC9.C2 (PGND_1), IC9.C3 (PGND_2), J2.3, J2.5, R1.1, R3.1, TP_GND.TP, U1.P$74 (VSS_PAD), U1.P$75 (VSS_PAD), U1.P$76 (VSS_PAD), U1.P$77 (VSS_PAD), U1.P$78 (VSS_PAD), U1.P$79 (VSS_PAD), U1.P$80 (VSS_PAD), U1.P$81 (VSS_PAD), U1.P$82 (VSS_PAD), U1.P$83 (VSS_PAD), U1.P$84 (VSS_PAD), U1.P$85 (VSS_PAD), U1.P$86 (VSS_PAD), U1.P$87 (VSS_PAD), U1.P$88 (VSS_PAD), U1.P$89 (VSS_PAD), U1.P$90 (VSS_PAD), U1.P$B7 (VSS), U1.P$F23 (VSS_PA), X1.2, X1.4; also elsewhere on the board
HAPTIC_EN/2.6A: U1.P$U1 (P0.12)
IMU_INT1: IC3.5 (INT1), U1.P$N1 (P0.08)
IMU_INT2: IC3.6 (INT2), U1.P$P2 (P1.08)
LX1: IC9.B2 (SW1_1), IC9.B3 (SW1_2), L7.1
LX2: IC9.D2 (SW2_1), IC9.D3 (SW2_2), L7.2
MOSI/2.2D: U1.P$B13 (P0.03/AIN1)
unnamed: C8.1, U1.P$AD23 (VDD)
unnamed: IC1.D1 (TS/MR), R1.2
unnamed: IC9.D1 (SCL), R4.2
unnamed: IC9.E1 (SDA), R2.2
unnamed: IC3.1 (SDO), R3.2
unnamed: C9.1, U1.P$N24 (DEC5)
unnamed: C3.1, L1.1, U1.P$H23 (ANT)
unnamed: L2.2, L3.1
unnamed: C10.1, C15.1, C16.1, L3.2, U1.P$B5 (DEC4), U1.P$E24 (DEC6)
unnamed: C11.1, U1.P$D23 (DEC3)
unnamed: C1.1, U1.P$B24 (XC1), X1.1
unnamed: C2.1, U1.P$A23 (XC2), X1.3
unnamed: ANT1.1 (FEED), C4.1, C22.1, L1.2
unnamed: C5.1, U1.P$C1 (DEC1)
unnamed: C13.1, U1.P$A18 (DEC2)
unnamed: C17.2, U1.P$D2 (P0.00/XL1), X2.2
unnamed: L2.1, U1.P$B3 (DCC)
unnamed: C14.1, U1.P$B1 (VDD)
unnamed: C18.2, U1.P$F2 (P0.01/XL2), X2.1
unnamed: C20.1, U1.P$AC5 (DEC3V3)
P0.04: U1.P$J1 (P0.04/AIN2)
P0.09: U1.P$L24 (P0.09/NFC1)
P0.13/2.6C: U1.P$AD8 (P0.13)
P0.14/2.7C: U1.P$AC9 (P0.14)
P0.19: U1.P$AC15 (P0.19)
P0.20: U1.P$AD16 (P0.20)
P0.21: U1.P$AC17 (P0.21)
P0.22: U1.P$AD18 (P0.22)
P0.23: U1.P$AC19 (P0.23)
P0.24: U1.P$AD20 (P0.24)
P0.25: U1.P$AC21 (P0.25)
P0.26: U1.P$G1 (P0.26)
P0.27: U1.P$H2 (P0.27)
P0.28: U1.P$B11 (P0.28/AIN4)
P0.29: U1.P$A10 (P0.29/AIN5)
P0.30: U1.P$B9 (P0.30/AIN6)
P0.31: U1.P$A8 (P0.31/AIN7)
P1.01/2.4B: U1.P$Y23 (P1.01)
P1.02/2.8C: U1.P$W24 (P1.02)
P1.03: U1.P$V23 (P1.03)
P1.04: U1.P$U24 (P1.04)
P1.05: U1.P$T23 (P1.05)
P1.06: U1.P$R24 (P1.06)
P1.07: U1.P$P23 (P1.07)
P1.09: U1.P$R1 (P1.09)
P1.10: U1.P$A20 (P1.10)
P1.11: U1.P$B19 (P1.11)
P1.12: U1.P$B17 (P1.12)
P1.13: U1.P$A16 (P1.13)
P1.14: U1.P$B15 (P1.14)
P1.15: U1.P$A14 (P1.15)
PMIC_INT: IC1.A1 (!INT), U1.P$T2 (P0.11)
RESET: J2.6, TP_RESET.TP, U1.P$AC13 (P0.18/RESET)
SCK/2.2D: U1.P$A12 (P0.02/AIN0)
SCL/2.4C: IC1.B1 (SCL), IC3.12 (SCX), R4.1, R17.2, TP_SCL.TP, U1.P$M2 (P0.07)
SDA/2.4C: IC1.C1 (SDA), IC3.2 (SDX), R2.1, R18.2, TP_SDA.TP, U1.P$L1 (P0.06)
SWDCLK: J2.4, TP_SWDCLK.TP, U1.P$AA24 (SWDCLK)
SWDIO: J2.2, TP_SWDIO.TP, U1.P$AC24 (SWDIO)
SWO: TP_SWO.TP, U1.P$AD22 (P1.00)
VBAT/2.5C: C37.2, IC1.C2 (BAT)
VBUS/2.6D: C21.1, C38.2, IC1.A2 (IN), U1.P$AD2 (VBUS)
VREG: C23.1, C24.2, C39.1, IC1.B2 (SYS), IC9.A1 (EN), IC9.A2 (VIN_1), IC9.A3 (VIN_2), TP_VREG.TP

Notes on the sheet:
LiPo Charger
DC/DC
DEC4_6
DEC3
IMU
SWD
Pana Teodor Cristian

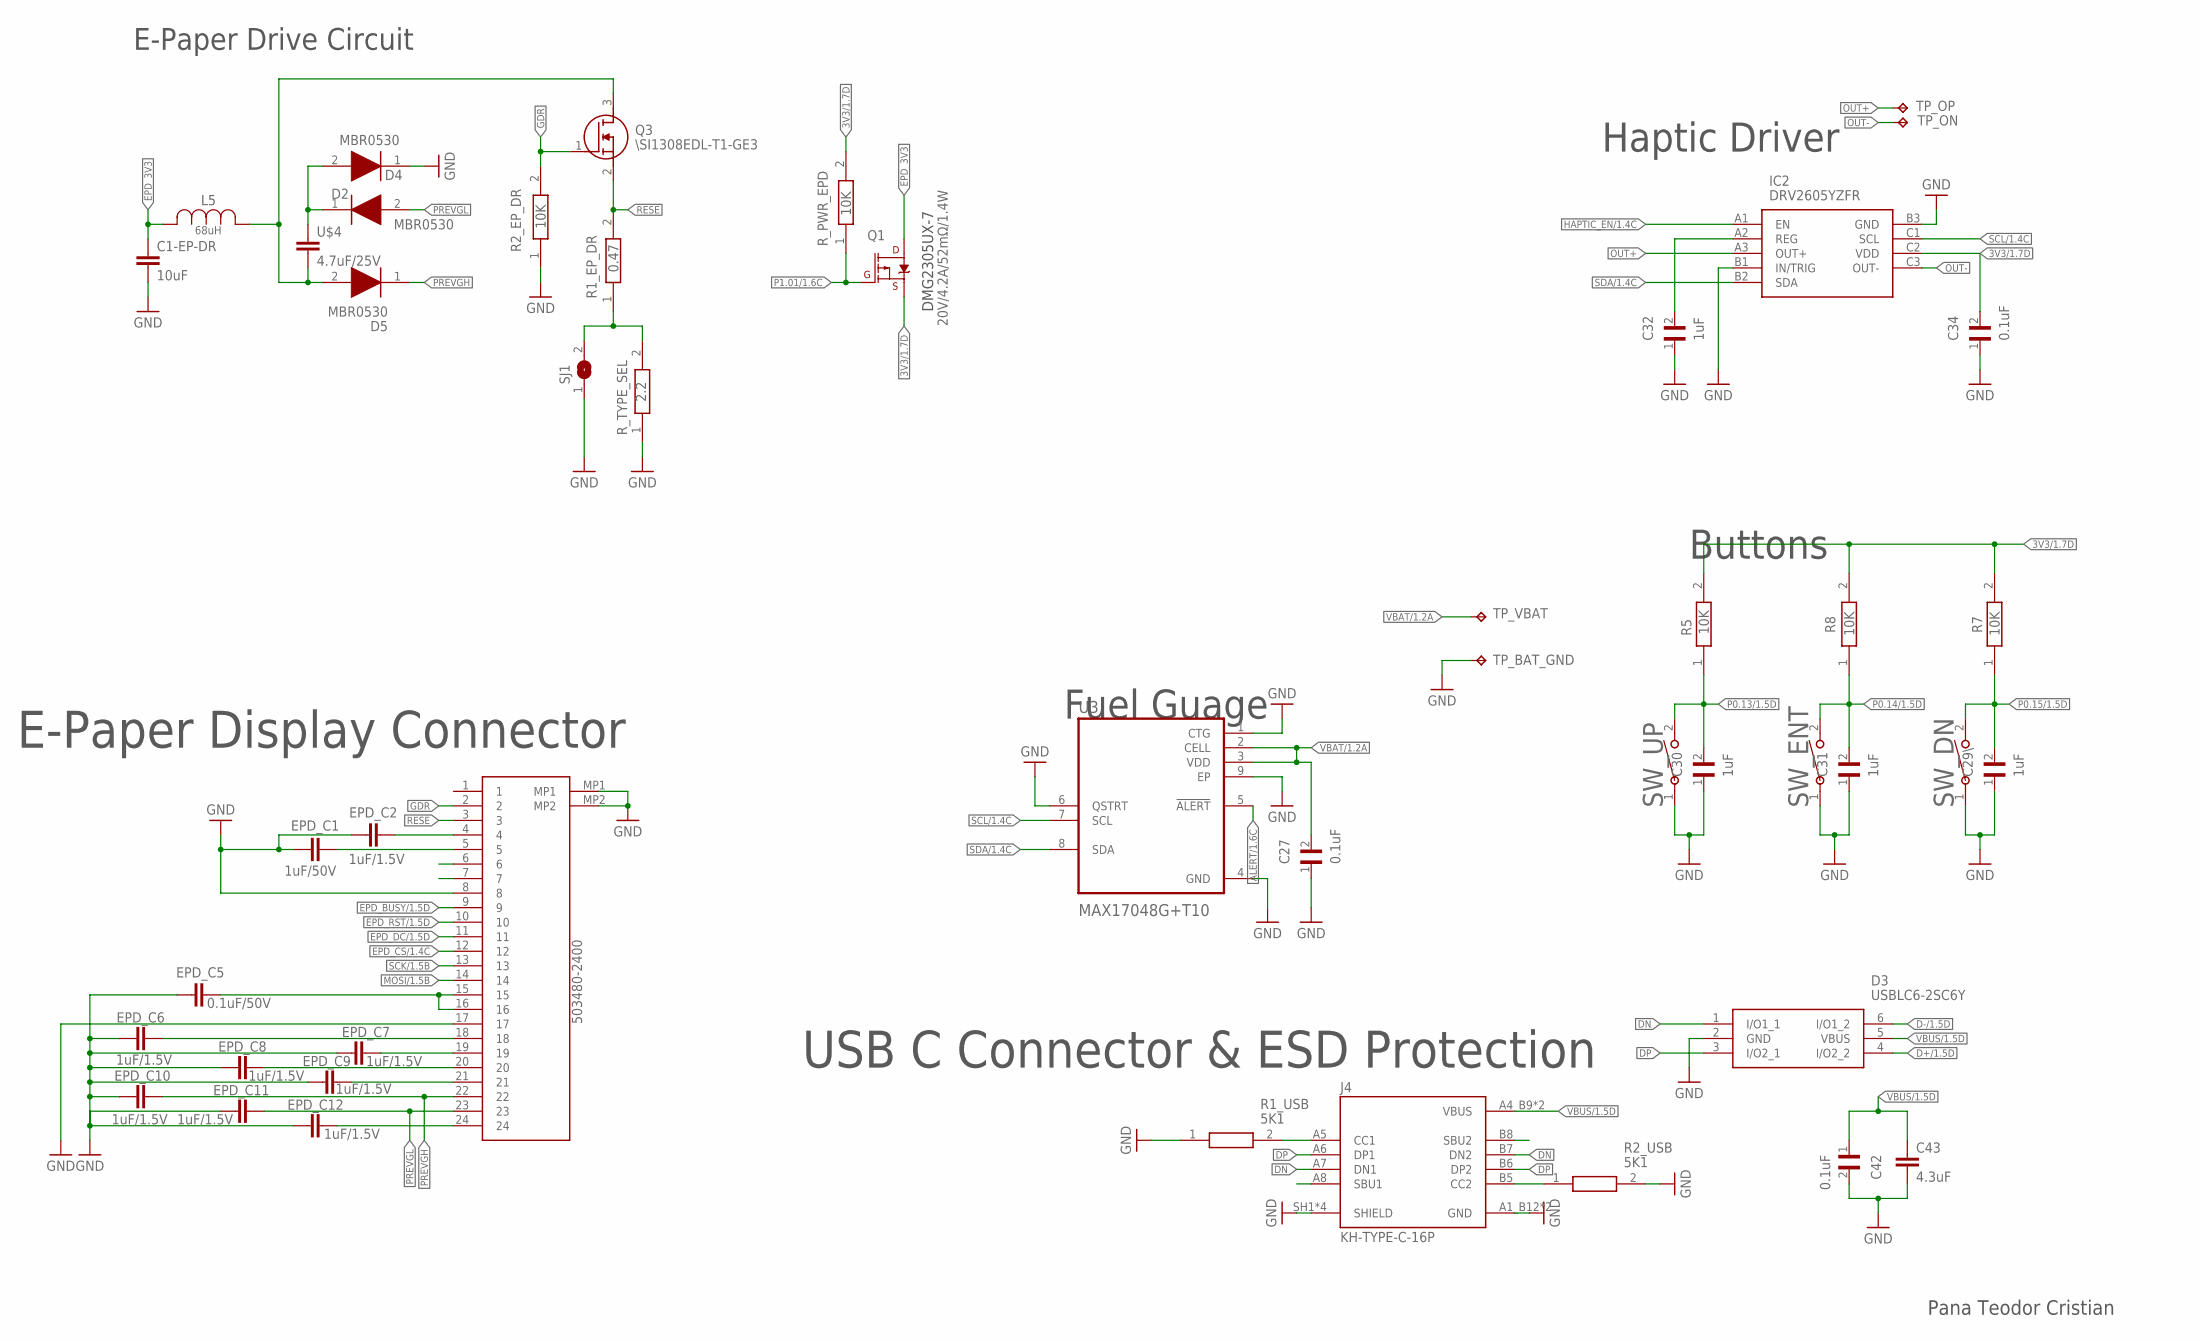
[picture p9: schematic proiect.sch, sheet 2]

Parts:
C1-EP-DR: 10uF; NORDIC_NRF_3_RESC0201_L
C27, C34, C42: 0.1uF; GRM011R60J152KE01L_2_CAPC0201X13N
C29\, C30, C31, C32: 1uF; GRM011R60J152KE01L_2_CAPC0201X13N
C43: 4.3uF; NORDIC_NRF_3_RESC0201_L
D2, D4, D5: MBR0530; ESP32_C6_LIBRARY_5_SOD3716X135N
D3: USBLC6-2SC6Y; ESP32_C6_LIBRARY_3_SOT95P280X145-6N
EPD_C1: 1uF/50V; PERFECT_0402_0402
EPD_C2, EPD_C6, EPD_C7, EPD_C8, EPD_C9, EPD_C10, EPD_C11, EPD_C12: 1uF/1.5V; PERFECT_0402_0402
EPD_C5: 0.1uF/50V; PERFECT_0402_0402
IC2: DRV2605YZFR; DRV2605YZFR_BGA9C50P3X3_144X144X62
J1: 503480-2400; 503480-2400_5034802400
J4: KH-TYPE-C-16P; KH-TYPE-C-16P_KINGHELM_KH-TYPE-C-16P
L5: 68uH; ESP32_C6_LIBRARY_2_IND_4828-WE-TPC_WRE
Q1: 20V/4.2A/52mΩ/1.4W; ESP32_C6_LIBRARY_4_ESP32_C6_LIBRARY_4_ESP32_C6_LIBRARY_4_ES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
Q3: \SI1308EDL-T1-GE3; ESP32_C6_LIBRARY_6_SOT65P210X110-3N
R1_EP_DR: 0.47; CPF0201D7K68C1_0201
R1_USB, R2_USB: 5K1; CPF0201D7K68C1_0201
R2_EP_DR, R5, R7, R8: 10K; CPF0201D7K68C1_0201
R_PWR_EPD: 10K; CPF0201D7K68C1_0201
R_TYPE_SEL: 2.2; CPF0201D7K68C1_0201
SJ1: ESP32_C6_LIBRARY_7_JUMPER_SJ
SW_DN: 2025-10-22_07-23-44_LIBRARY_EVP-AKE31ASW_EVP-AKE3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; 2025-10-22_07-23-44_LIBRARY_SW_EVP-AKE31A_PAN
SW_ENT: 2025-10-22_07-23-44_LIBRARY_EVP-AKE31ASW_EVP-AKE3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; 2025-10-22_07-23-44_LIBRARY_SW_EVP-AKE31A_PAN
SW_UP: 2025-10-22_07-23-44_LIBRARY_EVP-AKE31ASW_EVP-AKE3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; 2025-10-22_07-23-44_LIBRARY_SW_EVP-AKE31A_PAN
TP_BAT_GND: HECTOR_WATCH_1_TPTP20R; HECTOR_WATCH_1_TP20R
TP_ON: HECTOR_WATCH_1_TPTP20R; HECTOR_WATCH_1_TP20R
TP_OP: HECTOR_WATCH_1_TPTP20R; HECTOR_WATCH_1_TP20R
TP_VBAT: HECTOR_WATCH_1_TPTP20R; HECTOR_WATCH_1_TP20R
U3: MAX17048G+T10; ESP32_C6_LIBRARY_SON50P200X200X80-9N
U$4: 4.7uF/25V; NORDIC_NRF_3_RESC0201_L

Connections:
3V3/1.7D: C34.2, IC2.C2 (VDD), Q1.2 (S), R5.2, R7.2, R8.2, R_PWR_EPD.2
ALERT/1.6C: U3.5 (!ALERT)
D+/1.5D: D3.4 (I/O2_2)
D-/1.5D: D3.6 (I/O1_2)
DN: D3.1 (I/O1_1), J4.A7 (DN1), J4.B7 (DN2)
DP: D3.3 (I/O2_1), J4.A6 (DP1), J4.B6 (DP2)
EPD_3V3: C1-EP-DR.1, L5.2, Q1.3 (D)
EPD_BUSY/1.5D: J1.9
EPD_CS/1.4C: J1.12
EPD_DC/1.5D: J1.11
EPD_RST/1.5D: J1.10
GDR: J1.2, Q3.1 (G), R2_EP_DR.2
GND: C1-EP-DR.2, C27.1, C29\.1, C30.1, C31.1, C32.1, C34.1, C42.2, C43.2, D3.2 (GND), D4.1 (K), EPD_C1.1, EPD_C2.1, EPD_C5.1, EPD_C6.1, EPD_C7.1, EPD_C8.1, EPD_C9.1, EPD_C10.1, EPD_C11.1, EPD_C12.1, IC2.B1 (IN/TRIG), IC2.B3 (GND), J1.8, J1.17, J1.MP1, J1.MP2, J4.A1_B12 (GND), J4.A12_B1 (GND), J4.SH1 (SHIELD), J4.SH2 (SHIELD), J4.SH3 (SHIELD), J4.SH4 (SHIELD), R1_USB.1, R2_EP_DR.1, R2_USB.2, R_TYPE_SEL.1, SJ1.1, SW_DN.1, SW_ENT.1, SW_UP.1, TP_BAT_GND.TP, U3.1 (CTG), U3.4 (GND), U3.6 (QSTRT), U3.9 (EP); also elsewhere on the board
HAPTIC_EN/1.4C: IC2.A1 (EN)
MOSI/1.5B: J1.14
unnamed: D5.2 (A), L5.1, Q3.3 (D), U$4.2
unnamed: D2.1 (K), D4.2 (A), U$4.1
unnamed: EPD_C2.2, J1.4
unnamed: EPD_C1.2, J1.5
unnamed: J4.B5 (CC2), R2_USB.1
unnamed: C32.2, IC2.A2 (REG)
unnamed: EPD_C5.2, J1.15, J1.16
unnamed: J4.A5 (CC1), R1_USB.2
unnamed: EPD_C6.2, J1.18
unnamed: EPD_C7.2, J1.19
unnamed: EPD_C8.2, J1.20
unnamed: EPD_C9.2, J1.21
unnamed: R1_EP_DR.1, R_TYPE_SEL.2, SJ1.2
unnamed: EPD_C12.2, J1.24
OUT+: IC2.A3 (OUT+), TP_OP.TP
OUT-: IC2.C3 (OUT-), TP_ON.TP
P0.13/1.5D: C30.2, R5.1, SW_UP.2
P0.14/1.5D: C31.2, R8.1, SW_ENT.2
P0.15/1.5D: C29\.2, R7.1, SW_DN.2
P1.01/1.6C: Q1.1 (G), R_PWR_EPD.1
PREVGH: D5.1 (K), EPD_C10.2, J1.22
PREVGL: D2.2 (A), EPD_C11.2, J1.23
RESE: J1.3, Q3.2 (S), R1_EP_DR.2
SCK/1.5B: J1.13
SCL/1.4C: IC2.C1 (SCL), U3.7 (SCL)
SDA/1.4C: IC2.B2 (SDA), U3.8 (SDA)
VBAT/1.2A: C27.2, TP_VBAT.TP, U3.2 (CELL), U3.3 (VDD)
VBUS/1.5D: C42.1, C43.1, D3.5 (VBUS), J4.A4_B9 (VBUS), J4.A9_B4 (VBUS)

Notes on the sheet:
E-Paper Display Connector
USB C Connector & ESD Protection
Fuel Guage
Buttons
Haptic Driver
E-Paper Drive Circuit
DMG2305UX-7
Pana Teodor Cristian

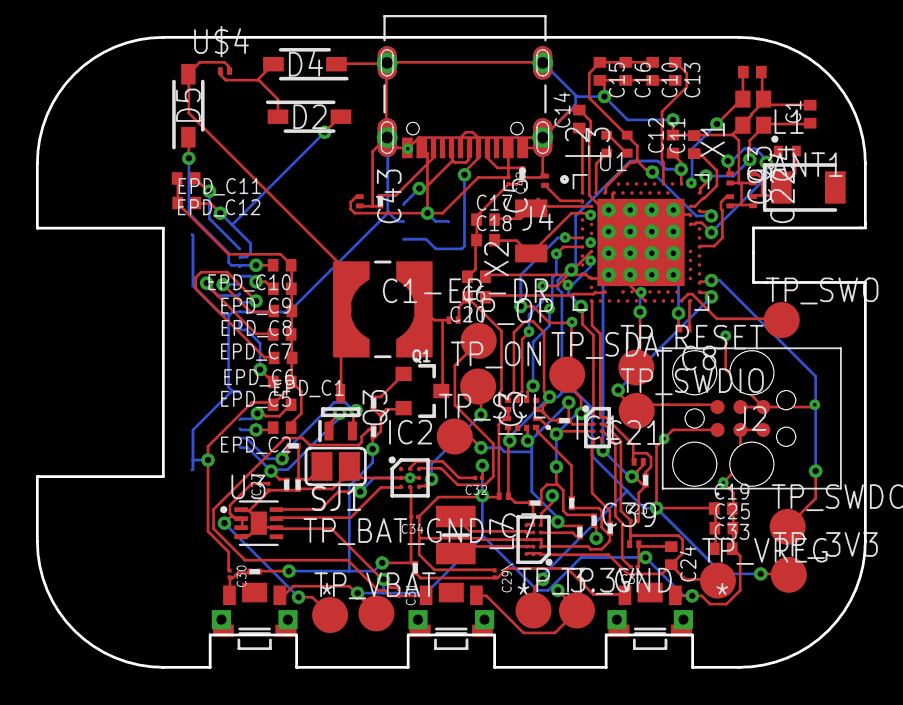
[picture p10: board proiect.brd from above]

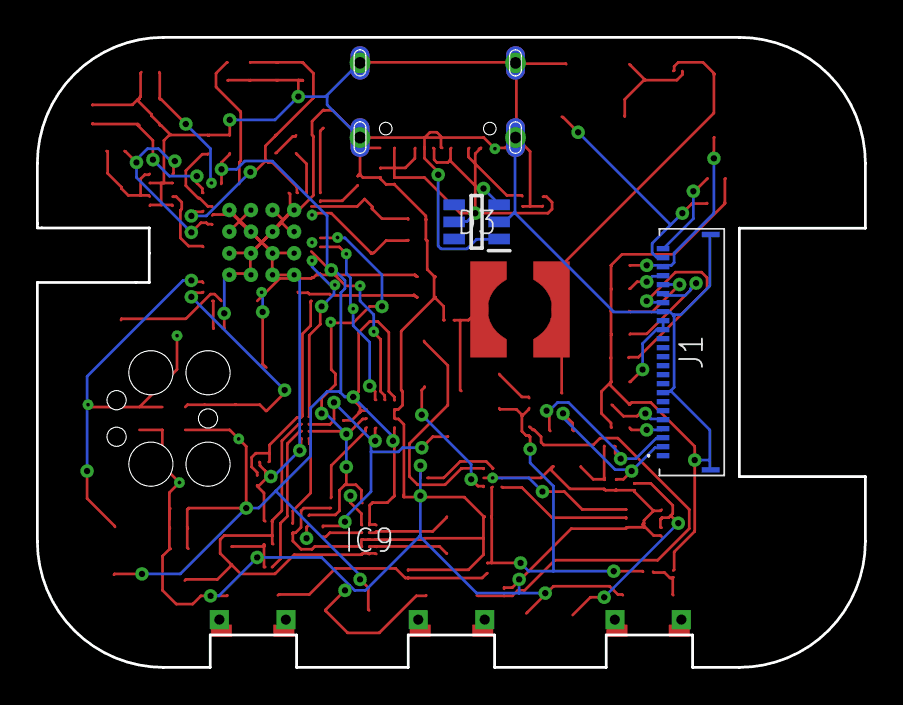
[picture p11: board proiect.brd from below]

Board: 4 copper layers, 46.0 x 35.0 mm, 105 parts (2 on the bottom side), 68 nets.

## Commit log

2026-04-10 Add files via upload
    schematic
    [proiect.sch]
2026-04-20 schematica gata
2026-04-20 update sch
    [proiect.sch]
2026-04-20 update brd
    [proiect.brd]

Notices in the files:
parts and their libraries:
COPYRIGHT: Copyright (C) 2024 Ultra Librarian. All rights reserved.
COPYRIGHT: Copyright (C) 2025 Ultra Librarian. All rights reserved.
